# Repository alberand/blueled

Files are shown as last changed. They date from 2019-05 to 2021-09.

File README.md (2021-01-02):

## Blueled - Bluetooth LED strip controller

This repo has hardware and firmware for Bluetooth LED strip controller based on
atmega328p (the same as in Arduino Nano).

Features:

* Android Application (not started yet)
* Custom colors and gradients
* ~15 different pre-set animation
* Over-The-Air Updates
* Python interface (to control it from PC)
* Save latest state between power on/off
* Up to 100 LEDs on full brightness (WS2812B)

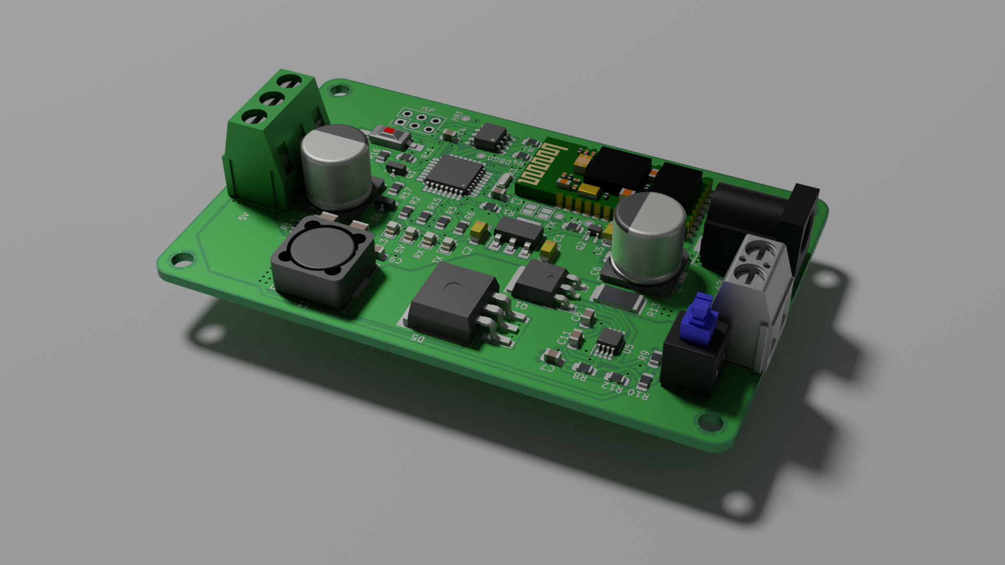
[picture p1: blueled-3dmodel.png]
PCB 3D Render


#### Notes (to refactor)

Be careful with connection between programmer Arduino and target Arduino. I had
a lot of corrupted bytes during uploading bootloader/application with ISCP.

Add bluetooth:

    $ sudo systemctl start bluetooth
    $ sudo bluetoothctl
    $ power on
    $ scan on
    $ # You will see MAC of your HC-05
    $ trust <MAC>
    $ pair <MAC>
    $ # It will ask for pin
    $ # That's all!

Load rfcomm kernel module:

    sudo modprobe rfcomm 

Create serial port:

    sudo rfcomm bind rfcomm0 <MAC>

How to sniff bluetooth:
https://github.com/snarlistic/jpnevulator

    jpnevulator --tty=/dev/blueled --read --ascii

In case of problems with PC's bluetooth module try:

1. power on/off module through the bluetoothctl session
2. sudo rfkill unblock all

https://gist.github.com/0/c73e2557d875446b9603

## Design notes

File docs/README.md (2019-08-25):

A lot of interesting articles at [1]

### Guides

Short instructions

#### How to get into AT mode

1. Upload serial-passthrough to your MCU
2. Connect to the bluetooth with Phone/another HC-05 to make sure that
   communication works
3. Put PIO11 high. Device will stop to reponse on serial link
4. Put RESET pin low
5. Put RESET pin high
6. Now you are in AT mode. Configure HC-05
7. Put PIO11 low
8. Reset chip again

### Notes

#### HC-Status PIO9

Seems to work but with delays.

### References

[1]: https://www.microchip.com/wwwproducts/en/ATSHA204A

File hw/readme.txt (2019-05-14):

Screw terminal:
https://www.gme.cz/svorkovnice-tl201v-03p-gs

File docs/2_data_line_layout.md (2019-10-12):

Author: Andrey Albershteyn
Date: 28.07.19
Status: Good Enough [Thrown away/Good Enough/Fully Solved]
Tags: hardware, layout

### Brief 

How to layout data line to the led strip? It is quite fast

### Timeline - Analysis & Solution

**[12.10.19]**

According to [this answer][1] the speed at which my device is operating is so
slow that it shouldn't be an issue for me. There are two main points to
consider:

* Signal integrity
* EMC

EMC can be caused by bad layout. 

* The shorter the line is the better. 
* Less vias better
* No sharp bends
[There][2] are a few good points on lay outing data lines

Signal integrity should be a problem in my case as it depends on slew/fall rate
which is quite slow in my case. 

There is no crosstalk in my case.

### References:

[1]: https://electronics.stackexchange.com/questions/9819/how-should-i-route-spi-lines
[2]: https://www.cypress.com/file/196526/download

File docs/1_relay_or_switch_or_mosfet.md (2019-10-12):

Author: Andrey Albershteyn
Date: 28.07.19
Status: Good Enough
Tags: feature, circuit-power-off

### Brief 

How to power off the whole device? With switch, relay or something else?

### Timeline - Analysis & Solution

**[28.07.19]**

I want to completely power off the circuit as I assume it more safe. No current
no problems. The following factors play role:

    * Humidity can create short circuit
    * High environment temperature + overheat on the output terminal
    * Low quality of Chinese components
    * Bug in the software (not fully disable led strip)
    * etc????

**[28.07.19]**

I find a few way how to power off the circuit:

    * Switch
    * Relay
    * MOSFET

**Switch** - very simple and cheap solution. However, the current in the circuit
is 5A. Therefore, I need some reliable high current switch. Unfortunately, all
of them are quite big for such a small device.

**Relay** - small, cheap, in combination with a small switch will give the same
functionality. The disadvantage is the *cwak* noise.

**MOSFET** - requires radiator which quite big.

**[29.07.19]**

According to this [1] using relay we get unwanted electromagnetic radiation
which is can be a problem for Bluetooth. I don't think it will broke it
completely but can decrease distance and quality of signal. The most of the
advantages of the relay doesn't suite for this application (such as AC
switching, isolation, robustness)

Mosfet is small and cheap and looks like it can be used as a switch. So, I don't
see why not use for this project.

I decided to you P-MOSFET. AOD4185L MOSFET P Trench 40V 40A 3V @ 250uA 15 mΩ @
20A,10V TO-252-2(DPAK) RoHS

Proof that it is used as reverse polarity [2]

### References

[1]: https://electronics.stackexchange.com/questions/10092/relay-vs-transistor
[2]: https://electronics.stackexchange.com/questions/61692/reverse-polarity-protection

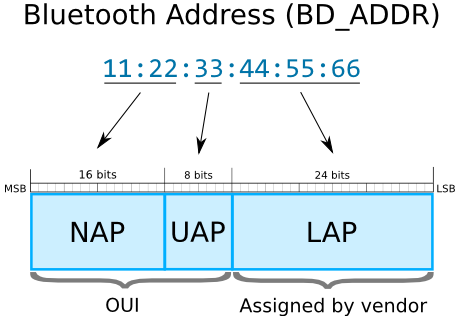
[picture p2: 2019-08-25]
docs/bluetooth-address-structure-nap-uap-lap.png

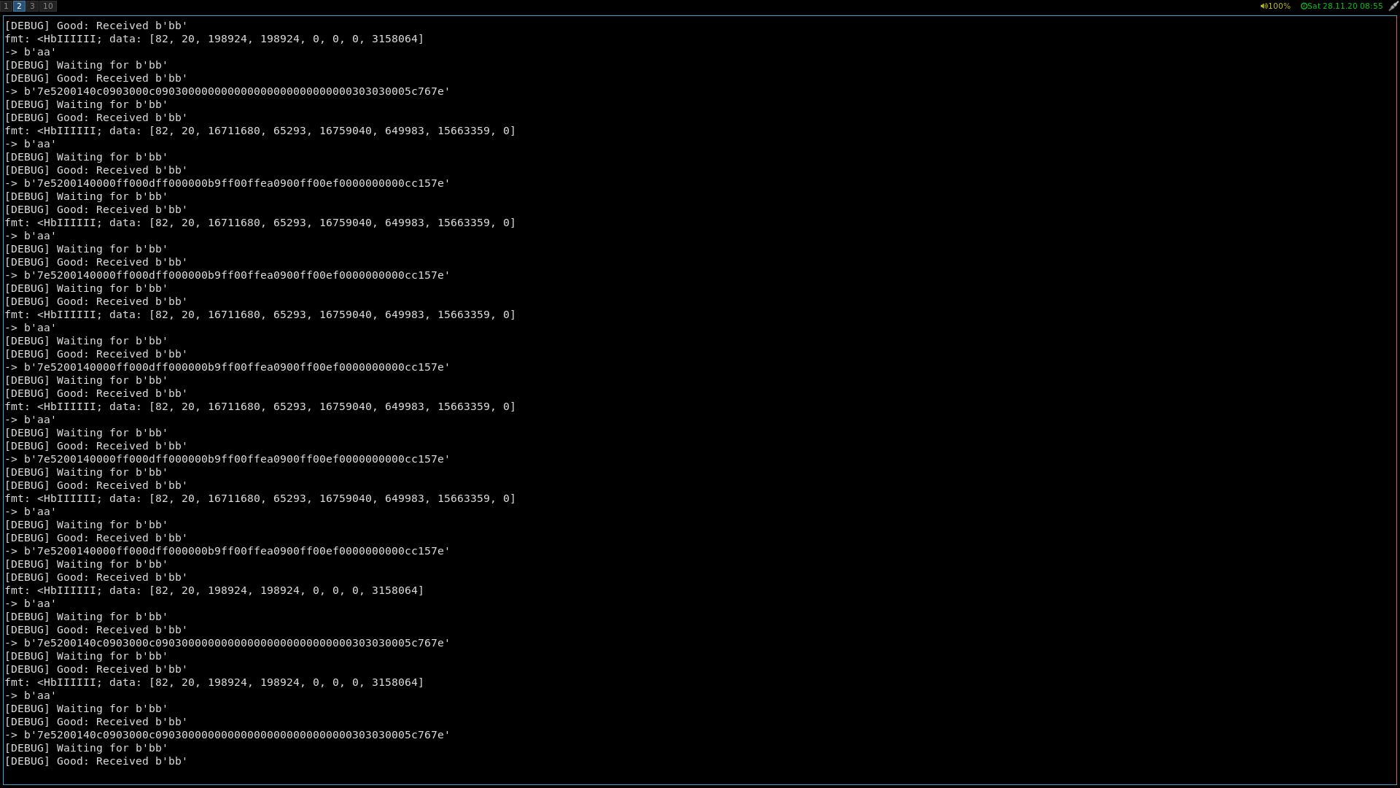
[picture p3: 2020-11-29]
scripts/monitor-1.png

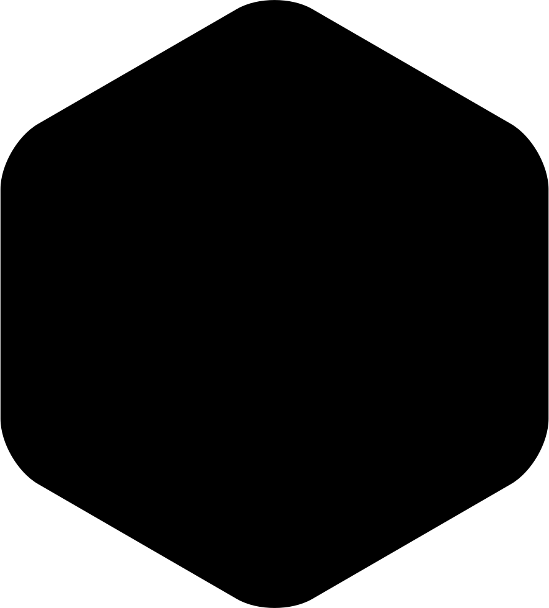
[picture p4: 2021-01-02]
hw/hexagon.png

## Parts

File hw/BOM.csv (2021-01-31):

Reference | Value | Footprint | Datasheet | Distributor | Manuf. Part | Field4 | Field6 | Field7 | Field8
J2 | LED Strip | TerminalBlock:TerminalBlock_bornier-3_P5.08mm | https://datasheet.lcsc.com/szlcsc/2004291906_Ningbo-Xinlaiya-Elec-XY2500R-D-5-08-3P_C505825.pdf | lcsc.com | XY2500R-D-5.08-3P
J1 | DC 5.5 - 42V | Connector_BarrelJack:BarrelJack_Horizontal | https://datasheet.lcsc.com/szlcsc/1912111437_XKB-Enterprise-DC-005-5A-2-0_C381116.pdf | lcsc.com | DC-005-5A-2.0
J3 | ICSP | Connector_PinHeader_2.54mm:PinHeader_2x03_P2.54mm_Vertical | ~
D3 | TX | LED_SMD:LED_0805_2012Metric_Pad1.15x1.40mm_HandSolder | https://datasheet.lcsc.com/szlcsc/1811141223_TOGIALED-TJ-S1608SW6TGLC2G-A5_C192316.pdf | lcsc.com | TJ-S1608SW6TGLC2R-A5
R6 | 150 | Resistor_SMD:R_0805_2012Metric_Pad1.15x1.40mm_HandSolder | https://datasheet.lcsc.com/szlcsc/YAGEO-RC0805FR-07150RL_C114523.pdf | lcsc.com | RC0805FR-07150RL
D2 | RX | LED_SMD:LED_0805_2012Metric_Pad1.15x1.40mm_HandSolder | https://datasheet.lcsc.com/szlcsc/1811141223_TOGIALED-TJ-S1608SW6TGLC2G-A5_C192316.pdf | lcsc.com | TJ-S1608SW6TGLC2R-A5
R3 | 150 | Resistor_SMD:R_0805_2012Metric_Pad1.15x1.40mm_HandSolder | https://datasheet.lcsc.com/szlcsc/YAGEO-RC0805FR-07150RL_C114523.pdf | lcsc.com | RC0805FR-07150RL
U2 | HC-05 | MOUDLE-BLUETOOTH-HC-05_34P-27X13MM_:BT34P-SMD-1.5-26.9X13.0X2.2MM | https://components101.com/sites/default/files/component_datasheet/HC-05%20Datasheet.pdf | aliexpress.com |  | Unavailable | SOIC-14 | HuiCheng | None
DBG1 | DBG-HC-PWR | TestPoint:TestPoint_Pad_D1.0mm | ~
JP1 | Jumper_NC_Small | Jumper:SolderJumper-2_P1.3mm_Bridged_Pad1.0x1.5mm | ~
JP2 | Jumper_NC_Small | Jumper:SolderJumper-2_P1.3mm_Bridged_Pad1.0x1.5mm | ~
J4 | DC 5.5 - 42V | TerminalBlock:TerminalBlock_bornier-2_P5.08mm | https://datasheet.lcsc.com/szlcsc/1912251632_Ningbo-Kangnex-Elec-WJ15EDGRC-3-81-2P_C8387.pdf | lcsc.com | WJ15EDGRC-3.81-2P
C5 | 22uF | Capacitor_Tantalum_SMD:CP_EIA-3216-18_Kemet-A_Pad1.58x1.35mm_HandSolder | https://datasheet.lcsc.com/szlcsc/1809131544_Vishay-Intertech-593D226X9004A2TE3_C215881.pdf | lcsc.com | 593D226X9004A2TE3
R5 | 1k | Resistor_SMD:R_0805_2012Metric_Pad1.15x1.40mm_HandSolder | https://datasheet.lcsc.com/szlcsc/1810010118_YAGEO-RC0805FR-071KL_C95781.pdf | lcsc.com | RC0805FR-071KL
DBG2 | DBG-HC-RST | TestPoint:TestPoint_Pad_D1.0mm | ~
D6 | BAS40-04 | Package_TO_SOT_SMD:SOT-23 | http://www.vishay.com/docs/85701/bas40v.pdf | lcsc.com | BAS40-04
H1 | MountingHole_Pad | MountingHole:MountingHole_3.2mm_M3 | ~
H2 | MountingHole_Pad | MountingHole:MountingHole_3.2mm_M3 | ~
H3 | MountingHole_Pad | MountingHole:MountingHole_3.2mm_M3 | ~
H4 | MountingHole_Pad | MountingHole:MountingHole_3.2mm_M3 | ~
C12 | 1000uF | Capacitor_SMD:CP_Elec_10x10 | https://datasheet.lcsc.com/szlcsc/1912111437_Lelon-VEU102M0JTR-1010_C249735.pdf | lcsc.com | VEU102M0JTR-1010
C6 | 33uF | Capacitor_SMD:CP_Elec_10x10 | https://datasheet.lcsc.com/szlcsc/1809291341_Lelon-VZH330M2ATR-1010_C249899.pdf | lcsc.com | VZH330M2ATR-1010
Q1 | Q_PMOS_SDG | Package_TO_SOT_SMD:TO-252-3_TabPin4 | https://datasheet.lcsc.com/szlcsc/Alpha-Omega-Semicon-AOS-AOD4185_C77993.pdf | lcsc.com | AOD4185L
C13 | 47uF | Capacitor_SMD:C_1210_3225Metric_Pad1.42x2.65mm_HandSolder | https://datasheet.lcsc.com/szlcsc/1912111437_TDK-C3225X5R0J476MT000N_C338024.pdf | lcsc.com | C3225X5R0J476MT000N
C1 | 10uF | Capacitor_Tantalum_SMD:CP_EIA-3216-18_Kemet-A_Pad1.58x1.35mm_HandSolder | https://datasheet.lcsc.com/szlcsc/AVX-TAJA106K016RNJ_C7171.pdf | lcsc.com | TAJA106K016RNJ
D4 | +5V | LED_SMD:LED_0805_2012Metric_Pad1.15x1.40mm_HandSolder | https://datasheet.lcsc.com/szlcsc/1811141223_TOGIALED-TJ-S1608SW6TGLC2G-A5_C192316.pdf | lcsc.com | TJ-S1608SW6TGLC2G-A5
R15 | 470 | Resistor_SMD:R_0805_2012Metric_Pad1.15x1.40mm_HandSolder | https://datasheet.lcsc.com/szlcsc/1810311431_YAGEO-RC0805FR-07470RL_C114564.pdf | lcsc.com | RC0805FR-07470RL
R14 | 0.27 | Resistor_SMD:R_0805_2012Metric_Pad1.15x1.40mm_HandSolder | https://datasheet.lcsc.com/szlcsc/2009282237_YAGEO-RL0805JR-070R27L_C705550.pdf | lcsc.com | RL0805JR-070R27L
R13 | 0.01 | Resistor_SMD:R_2512_6332Metric_Pad1.52x3.35mm_HandSolder | https://datasheet.lcsc.com/szlcsc/2008171235_YAGEO-RL2512JK-070R01L_C705618.pdf | lcsc.com | RL2512JK-070R01L
C7 | 680nF | Capacitor_SMD:C_0805_2012Metric_Pad1.15x1.40mm_HandSolder | https://datasheet.lcsc.com/szlcsc/2004221632_TDK-C2012X7S2A684KT000N_C516764.pdf | lcsc.com | C2012X7S2A684KT000N
U5 | LM25085MM | Package_SO:VSSOP-8_3.0x3.0mm_P0.65mm | http://www.ti.com/lit/ds/symlink/lm25085.pdf | lcsc.com | LM25085MM/NOPB
R10 | 10k | Resistor_SMD:R_0805_2012Metric_Pad1.15x1.40mm_HandSolder | https://datasheet.lcsc.com/szlcsc/1810201611_YAGEO-RC0805FR-0710KL_C84376.pdf | lcsc.com | RC0805FR-0710KL
C8 | 0.47uF | Capacitor_SMD:C_0805_2012Metric_Pad1.15x1.40mm_HandSolder | https://datasheet.lcsc.com/szlcsc/2009111606_TDK-C2012X7R1C474KT000N_C694187.pdf | lcsc.com | C2012X7R1C474KT000N
R8 | 90.9 | Resistor_SMD:R_0805_2012Metric_Pad1.15x1.40mm_HandSolder | https://datasheet.lcsc.com/szlcsc/1810301711_KOA-Speer-Elec-RK73B2ATTD102J_C159911.pdf | lcsc.com | RK73B2ATTD102J
C11 | 1nF | Capacitor_SMD:C_0805_2012Metric_Pad1.15x1.40mm_HandSolder | https://datasheet.lcsc.com/szlcsc/1912111437_TDK-C2012X7R2A102KT020S_C415298.pdf | lcsc.com | C2012X7R2A102KT020S
R12 | 2.1k | Resistor_SMD:R_0805_2012Metric_Pad1.15x1.40mm_HandSolder | https://datasheet.lcsc.com/szlcsc/2001062136_YAGEO-RC0805FR-072K1L_C273922.pdf | lcsc.com | RC0805FR-072K1L
R9 | 3.4k | Resistor_SMD:R_0805_2012Metric_Pad1.15x1.40mm_HandSolder | https://datasheet.lcsc.com/szlcsc/YAGEO-AC0805FR-073K4L_C228795.pdf | lcsc.com | RC0805FR-073K4L
C10 | 47uF | Capacitor_SMD:C_1210_3225Metric_Pad1.42x2.65mm_HandSolder | https://datasheet.lcsc.com/szlcsc/1912111437_TDK-C3225X5R0J476MT000N_C338024.pdf | lcsc.com | C3225X5R0J476MT000N
L1 | 15uH | blueled:SMMS1350-150M | https://datasheet.lcsc.com/szlcsc/1912111437_Sunlord-MWSA1004S-150MT_C408488.pdf | lcsc.com | MWSA1004S-150MT
D5 | MBRB2060 | Package_TO_SOT_SMD:TO-263-3_TabPin2 | https://datasheet.lcsc.com/szlcsc/Sangdest-Microelectronicstronic-Nanjing-MBRB2060CT_C260296.pdf | lcsc.com | MBRB2060CT
C9 | 4700pF | Capacitor_SMD:C_0805_2012Metric_Pad1.15x1.40mm_HandSolder | https://datasheet.lcsc.com/szlcsc/1912111437_TDK-C2012C0G1H472JT0H0N_C342964.pdf | lcsc.com | C2012C0G1H472JT0H0N
S1 | SWITCH-DPDT-PTH-GPI-152-3013 | blueled:XKB7070-Z | https://datasheet.lcsc.com/szlcsc/2002271810_XKB-Enterprise-XKB7070-Z_C318863.pdf | lcsc.com | XKB7070-Z | SWCH-10554
C2 | 22uF | Capacitor_Tantalum_SMD:CP_EIA-3216-18_Kemet-A_Pad1.58x1.35mm_HandSolder | https://datasheet.lcsc.com/szlcsc/1809131544_Vishay-Intertech-593D226X9004A2TE3_C215881.pdf | lcsc.com | 593D226X9004A2TE3
D1 | +3.3V | LED_SMD:LED_0805_2012Metric_Pad1.15x1.40mm_HandSolder | https://datasheet.lcsc.com/szlcsc/1811141223_TOGIALED-TJ-S1608SW6TGLC2G-A5_C192316.pdf | lcsc.com | TJ-S1608SW6TGLC2G-A5
R2 | 150 | Resistor_SMD:R_0805_2012Metric_Pad1.15x1.40mm_HandSolder | https://datasheet.lcsc.com/szlcsc/YAGEO-RC0805FR-07150RL_C114523.pdf | lcsc.com | RC0805FR-07150RL
U3 | AMS1117-3.3 | Package_TO_SOT_SMD:SOT-223 | http://www.ti.com/lit/ds/symlink/lm1117.pdf | lcsc.com | AMS1117-3.3
R7 | 1k | Resistor_SMD:R_0805_2012Metric_Pad1.15x1.40mm_HandSolder | https://datasheet.lcsc.com/szlcsc/1810010118_YAGEO-RC0805FR-071KL_C95781.pdf | lcsc.com | RC0805FR-071KL
C4 | 100n | Capacitor_SMD:C_0805_2012Metric_Pad1.15x1.40mm_HandSolder | https://datasheet.lcsc.com/szlcsc/1810191215_Samsung-Electro-Mechanics-CL21B104KBCNNNC_C1711.pdf | lcsc.com | CL21B104KBCNNNC
R4 | 1k | Resistor_SMD:R_0805_2012Metric_Pad1.15x1.40mm_HandSolder | https://datasheet.lcsc.com/szlcsc/1810010118_YAGEO-RC0805FR-071KL_C95781.pdf | lcsc.com | RC0805FR-071KL
U4 | AT25SF081 | Package_SO:SOIC-8_3.9x4.9mm_P1.27mm | https://www.adestotech.com/wp-content/uploads/DS-AT25SF081_045.pdf | lcsc.com | AT25SF081-SHD-T
R17 | 1k | Resistor_SMD:R_0805_2012Metric_Pad1.15x1.40mm_HandSolder | https://datasheet.lcsc.com/szlcsc/1810010118_YAGEO-RC0805FR-071KL_C95781.pdf | lcsc.com | RC0805FR-071KL
R16 | 1k | Resistor_SMD:R_0805_2012Metric_Pad1.15x1.40mm_HandSolder | https://datasheet.lcsc.com/szlcsc/1810010118_YAGEO-RC0805FR-071KL_C95781.pdf | lcsc.com | RC0805FR-071KL
Q3 | BSS138 | Package_TO_SOT_SMD:SOT-23 | https://datasheet.lcsc.com/szlcsc/AnBon-BSS138_C193019.pdf | lcsc.com | BSS138
R11 | 470 | Resistor_SMD:R_0805_2012Metric_Pad1.15x1.40mm_HandSolder | https://datasheet.lcsc.com/szlcsc/1810311431_YAGEO-RC0805FR-07470RL_C114564.pdf | lcsc.com | RC0805FR-07470RL
HRT1 | Heartbeat | TestPoint:TestPoint_Pad_D1.0mm | ~
X1 | CSTCE | blueled:Resonator_SMD_muRata_CSTNE_3Pin_3.2x1.3mm | https://datasheet.lcsc.com/szlcsc/1912111437_Murata-Electronics-CSTNE8M00G55Z000R0_C341524.pdf | lcsc.com | CSTNE8M00G55Z000R0
R1 | 1k | Resistor_SMD:R_0805_2012Metric_Pad1.15x1.40mm_HandSolder | https://datasheet.lcsc.com/szlcsc/1810010118_YAGEO-RC0805FR-071KL_C95781.pdf | lcsc.com | RC0805FR-071KL
SW2 | PUSH | Button_Switch_SMD:SW_SPST_FSMSM | https://datasheet.lcsc.com/szlcsc/1811082126_Korean-Hroparts-Elec-K2-1107ST-A4SW-06_C118141.pdf | lcsc.com | K2-1107ST-A4SW-06
DBG0 | Debug | TestPoint:TestPoint_Pad_D1.0mm | ~
C3 | 100n | Capacitor_SMD:C_0805_2012Metric_Pad1.15x1.40mm_HandSolder | https://datasheet.lcsc.com/szlcsc/1810191215_Samsung-Electro-Mechanics-CL21B104KBCNNNC_C1711.pdf | lcsc.com | CL21B104KBCNNNC
U1 | ATmega328P-AU | Package_QFP:TQFP-32_7x7mm_P0.8mm | http://ww1.microchip.com/downloads/en/DeviceDoc/ATmega328_P%20AVR%20MCU%20with%20picoPower%20Technology%20Data%20Sheet%2040001984A.pdf | lcsc.com | ATmega328P-AU
Q4 | Q_PMOS_GSD | Package_TO_SOT_SMD:SOT-23 | https://datasheet.lcsc.com/szlcsc/1912111437_UMW-Youtai-Semiconductor-Co-Ltd-IRLML6402_C347504.pdf | lcsc.com | IRLML6402

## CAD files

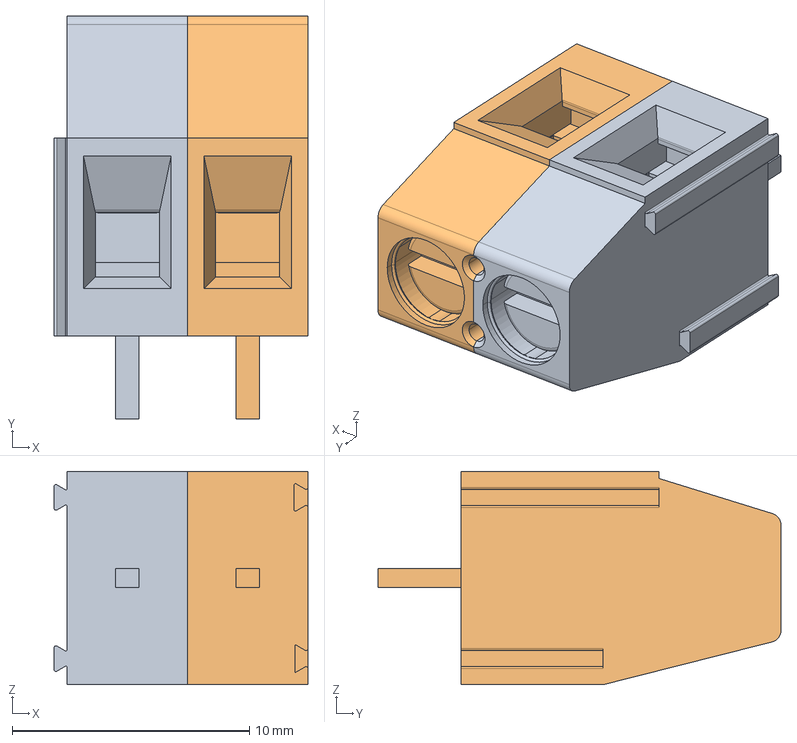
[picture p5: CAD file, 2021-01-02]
hw/3dmodels/terminal-block-2.stp
10.7 x 17.0 x 9.00 mm

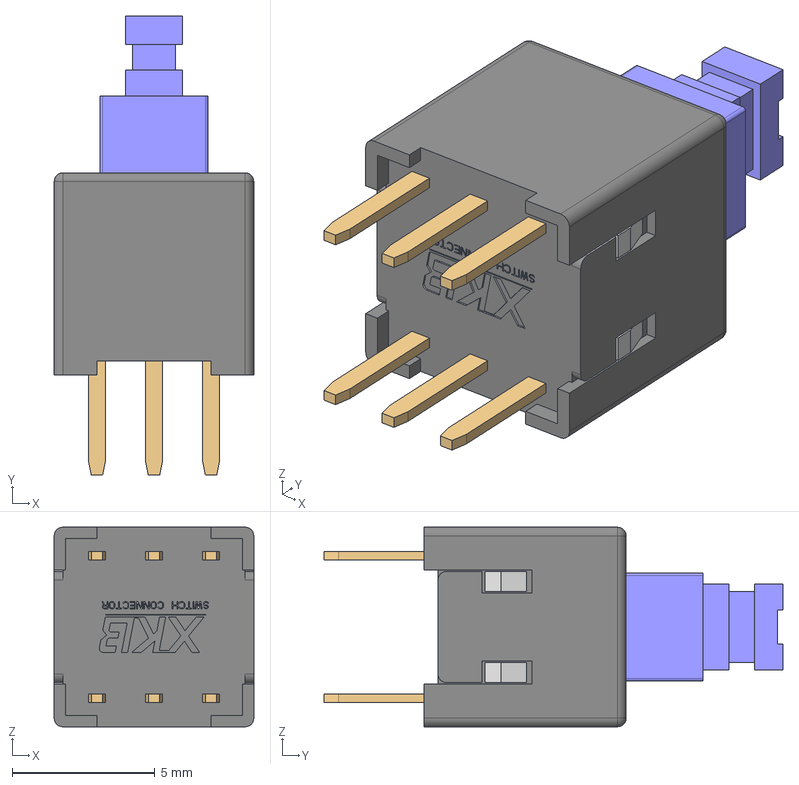
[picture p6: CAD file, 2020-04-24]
hw/3dmodels/xkb7070-z.step
7.00 x 16.1 x 7.00 mm

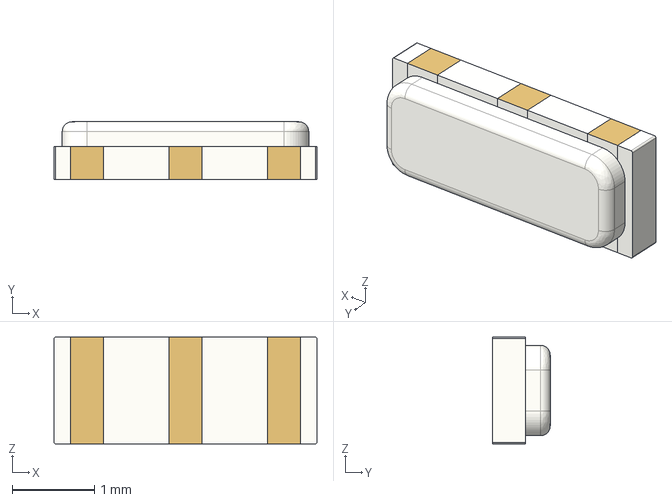
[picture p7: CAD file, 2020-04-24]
hw/3dmodels/CSTNE.step
3.20 x 0.7 x 1.30 mm

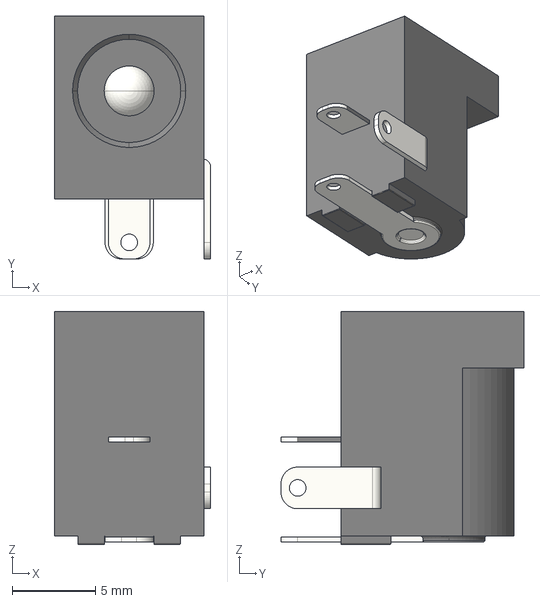
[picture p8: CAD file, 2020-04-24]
hw/3dmodels/dc-005-5a-2_0.step
9.40 x 14.6 x 14.0 mm

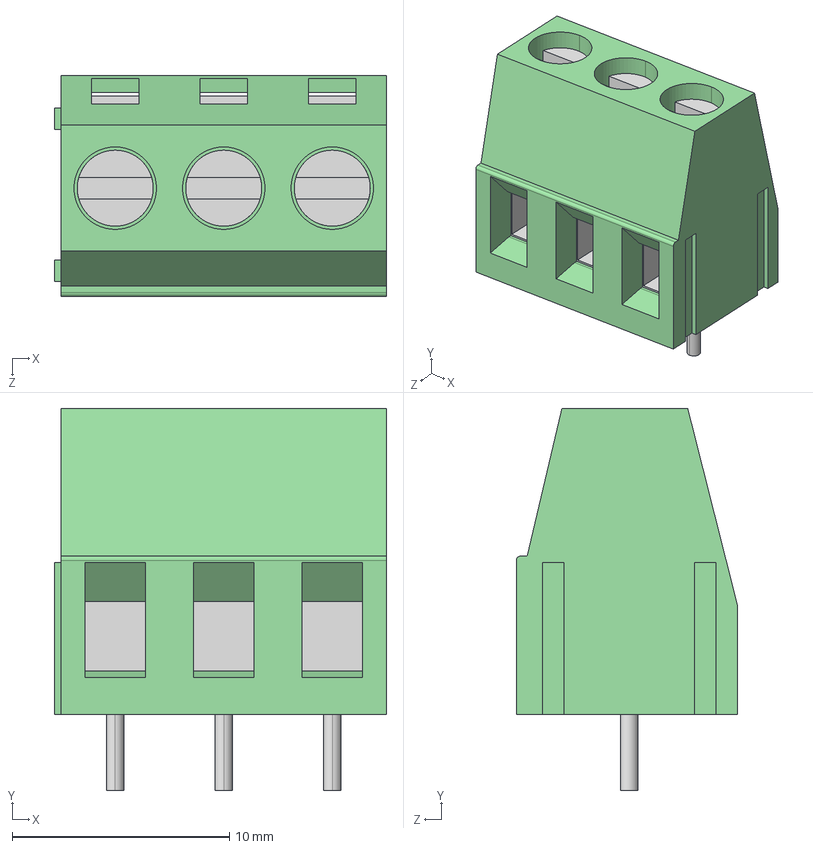
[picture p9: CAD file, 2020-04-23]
hw/3dmodels/kf120-5.0-3p.step
15.3 x 17.6 x 10.2 mm

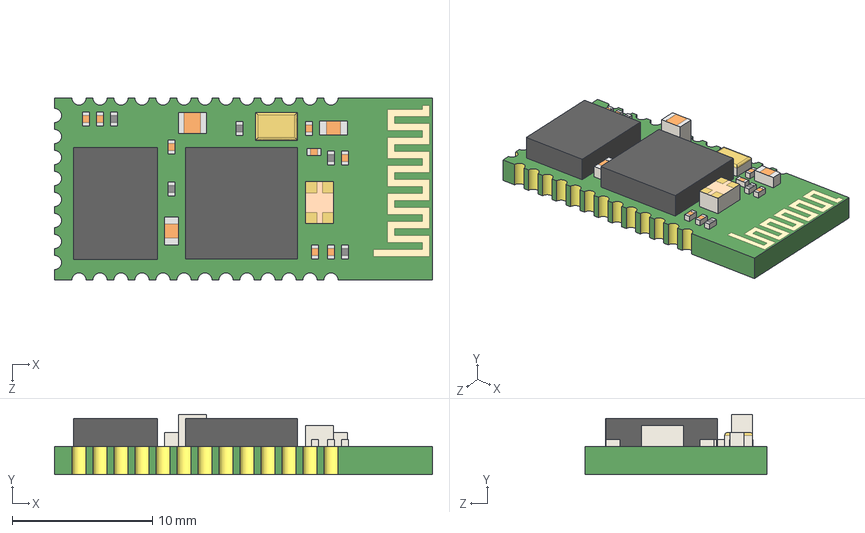
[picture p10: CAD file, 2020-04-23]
hw/3dmodels/HC-05.step
27.0 x 4.31 x 13.0 mm

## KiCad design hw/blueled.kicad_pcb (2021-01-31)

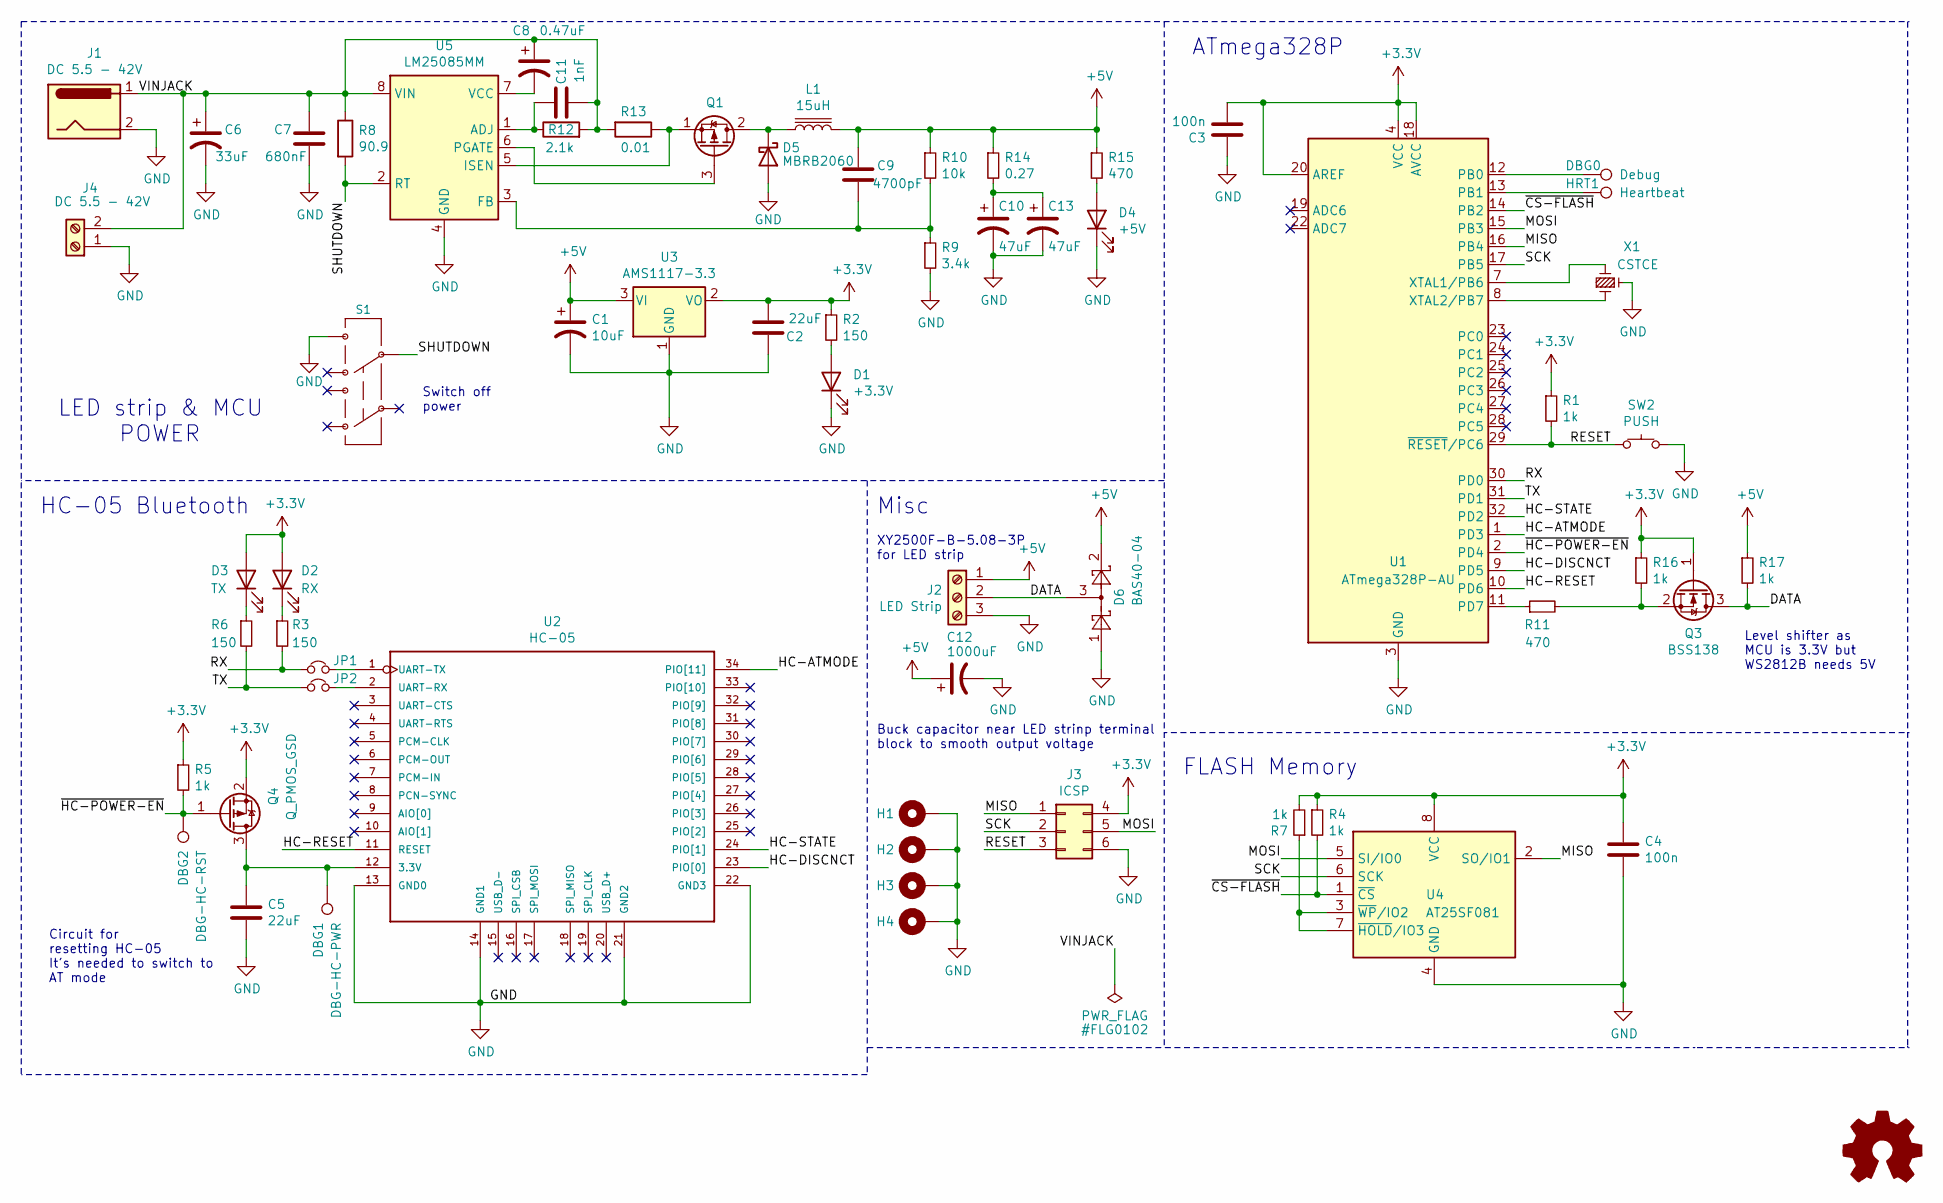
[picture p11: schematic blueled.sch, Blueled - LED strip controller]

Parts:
C1: 10uF; CP_EIA-3216-18_Kemet-A_Pad1.58x1.35mm_HandSolder; Manuf. Part TAJA106K016RNJ
C2, C5: 22uF; CP_EIA-3216-18_Kemet-A_Pad1.58x1.35mm_HandSolder; Manuf. Part 593D226X9004A2TE3
C3, C4: 100n; C_0805_2012Metric_Pad1.15x1.40mm_HandSolder; Manuf. Part CL21B104KBCNNNC
C6: 33uF; CP_Elec_10x10; Manuf. Part VZH330M2ATR-1010
C7: 680nF; C_0805_2012Metric_Pad1.15x1.40mm_HandSolder; Manuf. Part C2012X7S2A684KT000N
C8: 0.47uF; C_0805_2012Metric_Pad1.15x1.40mm_HandSolder; Manuf. Part C2012X7R1C474KT000N
C9: 4700pF; C_0805_2012Metric_Pad1.15x1.40mm_HandSolder; Manuf. Part C2012C0G1H472JT0H0N
C10, C13: 47uF; C_1210_3225Metric_Pad1.42x2.65mm_HandSolder; Manuf. Part C3225X5R0J476MT000N
C11: 1nF; C_0805_2012Metric_Pad1.15x1.40mm_HandSolder; Manuf. Part C2012X7R2A102KT020S
C12: 1000uF; CP_Elec_10x10; Manuf. Part VEU102M0JTR-1010
D1: +3.3V; LED_0805_2012Metric_Pad1.15x1.40mm_HandSolder; Manuf. Part TJ-S1608SW6TGLC2G-A5
D2: RX; LED_0805_2012Metric_Pad1.15x1.40mm_HandSolder; Manuf. Part TJ-S1608SW6TGLC2R-A5
D3: TX; LED_0805_2012Metric_Pad1.15x1.40mm_HandSolder; Manuf. Part TJ-S1608SW6TGLC2R-A5
D4: +5V; LED_0805_2012Metric_Pad1.15x1.40mm_HandSolder; Manuf. Part TJ-S1608SW6TGLC2G-A5
D5: MBRB2060; TO-263-3_TabPin2; Manuf. Part MBRB2060CT
D6: BAS40-04; SOT-23; Manuf. Part BAS40-04
DBG0: Debug; TestPoint_Pad_D1.0mm
DBG1: DBG-HC-PWR; TestPoint_Pad_D1.0mm
DBG2: DBG-HC-RST; TestPoint_Pad_D1.0mm
H1, H2, H3, H4: MountingHole_Pad; MountingHole_3.2mm_M3
HRT1: Heartbeat; TestPoint_Pad_D1.0mm
J1: DC 5.5 - 42V; BarrelJack_Horizontal; Manuf. Part DC-005-5A-2.0
J2: LED Strip; TerminalBlock_bornier-3_P5.08mm; Manuf. Part XY2500R-D-5.08-3P
J3: ICSP; PinHeader_2x03_P2.54mm_Vertical
J4: DC 5.5 - 42V; TerminalBlock_bornier-2_P5.08mm; Manuf. Part WJ15EDGRC-3.81-2P
JP1, JP2: Jumper_NC_Small; SolderJumper-2_P1.3mm_Bridged_Pad1.0x1.5mm
L1: 15uH; SMMS1350-150M; Manuf. Part MWSA1004S-150MT
Q1: Q_PMOS_SDG; TO-252-3_TabPin4; Manuf. Part AOD4185L
Q3: BSS138; SOT-23; Manuf. Part BSS138
Q4: Q_PMOS_GSD; SOT-23; Manuf. Part IRLML6402
R1, R4, R5, R7, R16, R17: 1k; R_0805_2012Metric_Pad1.15x1.40mm_HandSolder; Manuf. Part RC0805FR-071KL
R2, R3, R6: 150; R_0805_2012Metric_Pad1.15x1.40mm_HandSolder; Manuf. Part RC0805FR-07150RL
R8: 90.9; R_0805_2012Metric_Pad1.15x1.40mm_HandSolder; Manuf. Part RK73B2ATTD102J
R9: 3.4k; R_0805_2012Metric_Pad1.15x1.40mm_HandSolder; Manuf. Part RC0805FR-073K4L
R10: 10k; R_0805_2012Metric_Pad1.15x1.40mm_HandSolder; Manuf. Part RC0805FR-0710KL
R11, R15: 470; R_0805_2012Metric_Pad1.15x1.40mm_HandSolder; Manuf. Part RC0805FR-07470RL
R12: 2.1k; R_0805_2012Metric_Pad1.15x1.40mm_HandSolder; Manuf. Part RC0805FR-072K1L
R13: 0.01; R_2512_6332Metric_Pad1.52x3.35mm_HandSolder; Manuf. Part RL2512JK-070R01L
R14: 0.27; R_0805_2012Metric_Pad1.15x1.40mm_HandSolder; Manuf. Part RL0805JR-070R27L
S1: SWITCH-DPDT-PTH-GPI-152-3013; XKB7070-Z; Manuf. Part XKB7070-Z
SW2: PUSH; SW_SPST_FSMSM; Manuf. Part K2-1107ST-A4SW-06
U1: ATmega328P-AU; TQFP-32_7x7mm_P0.8mm; Manuf. Part ATmega328P-AU
U2: HC-05; BT34P-SMD-1.5-26.9X13.0X2.2MM
U3: AMS1117-3.3; SOT-223; Manuf. Part AMS1117-3.3
U4: AT25SF081; SOIC-8_3.9x4.9mm_P1.27mm; Manuf. Part AT25SF081-SHD-T
U5: LM25085MM; VSSOP-8_3.0x3.0mm_P0.65mm; Manuf. Part LM25085MM/NOPB
X1: CSTCE; Resonator_SMD_muRata_CSTNE_3Pin_3.2x1.3mm; Manuf. Part CSTNE8M00G55Z000R0

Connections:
+3V3: C2.2, C3.2, C4.1, D2.2 (A), D3.2 (A), J3.4, Q3.1 (G), Q4.2 (S), R1.1, R2.1, R4.1, R5.1, R7.2, R16.1, U1.4 (VCC), U1.6 (VCC), U1.18 (AVCC), U1.20 (AREF), U3.2 (VO), U4.8 (VCC); also elsewhere on the board
+5V: C1.1, C9.1, C12.1, D6.2, J2.1, L1.2, R10.1, R14.1, R15.1, R17.1, U3.3 (VI)
/DATA: D6.3, J2.2, Q3.3 (D), R17.2
/HC-ATMODE: U1.1 (PD3), U2.34 (PIO[11])
/HC-DISCNCT: U1.9 (PD5), U2.23 (PIO[0])
/HC-RESET: U1.10 (PD6), U2.11 (RESET)
/HC-STATE: U1.32 (PD2), U2.24 (PIO[1])
/MISO: J3.1, U1.16 (PB4), U4.2 (SO/IO1)
/MOSI: J3.5, U1.15 (PB3), U4.5 (SI/IO0)
/RESET: J3.3, R1.2, SW2.1, U1.29 (~RESET~/PC6)
/RX: JP1.1, R3.2, U1.30 (PD0)
/SCK: J3.2, U1.17 (PB5), U4.6 (SCK)
/SHUTDOWN: R8.2, S1.5, U5.2 (RT)
/TX: JP2.1, R6.2, U1.31 (PD1)
/VINJACK: C6.1, C7.1, C8.1, C11.1, J1.1, J4.2, R8.1, R12.2, R13.2, U5.8 (VIN); also elsewhere on the board
/~CS-FLASH: R4.2, U1.14 (PB2), U4.1 (~CS)
/~HC-POWER-EN: DBG2.1, Q4.1 (G), R5.2, U1.2 (PD4)
GND: C1.2, C2.1, C3.1, C4.2, C5.2, C6.2, C7.2, C10.2, C12.2, C13.2, D1.1 (K), D4.1 (K), D5.2 (A), D6.1, H1.1, H2.1, H3.1, H4.1, J1.2, J2.3, J3.6, J4.1, R9.2, S1.6, SW2.2, U1.3 (GND), U1.5 (GND), U1.21 (GND), U2.13 (GND0), U2.14 (GND1), U2.21 (GND2), U2.22 (GND3), U3.1 (GND), U4.4 (GND), U5.4 (GND), X1.2; also elsewhere on the board
unnamed: C5.1, DBG1.1, Q4.3 (D), U2.12 (3.3V)
unnamed: C8.2, U5.7 (VCC)
unnamed: C9.2, R9.1, R10.2, U5.3 (FB)
unnamed: C10.1, C13.1, R14.2
unnamed: C11.2, R12.1, U5.1 (ADJ)
unnamed 23: D1.2 (A), R2.2; also elsewhere on the board
unnamed 24: D2.1 (K), R3.1; also elsewhere on the board
unnamed 25: D3.1 (K), R6.1; also elsewhere on the board
unnamed 26: D4.2 (A), R15.2; also elsewhere on the board
unnamed: D5.1 (K), L1.1, Q1.2 (D)
unnamed: DBG0.1, U1.12 (PB0)
unnamed: HRT1.1, U1.13 (PB1)
unnamed: JP1.2, U2.1 (UART-TX)
unnamed: JP2.2, U2.2 (UART-RX)
unnamed: Q1.1 (S), R13.1, U5.5 (ISEN)
unnamed: Q1.3 (G), U5.6 (PGATE)
unnamed: Q3.2 (S), R11.2, R16.2
unnamed: R7.1, U4.3 (~WP~/IO2), U4.7 (~HOLD~/IO3)
unnamed: R11.1, U1.11 (PD7)
unnamed: U1.7 (XTAL1/PB6), X1.3
unnamed: U1.8 (XTAL2/PB7), X1.1

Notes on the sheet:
Misc
HC-05 Bluetooth
LED strip & MCU POWER
Buck capacitor near LED strinp terminal block to smooth output voltage
Circuit for resetting HC-05 It's needed to switch to AT mode
XY2500F-B-5.08-3P for LED strip
Switch off power
FLASH Memory
ATmega328P
Level shifter as MCU is 3.3V but WS2812B needs 5V

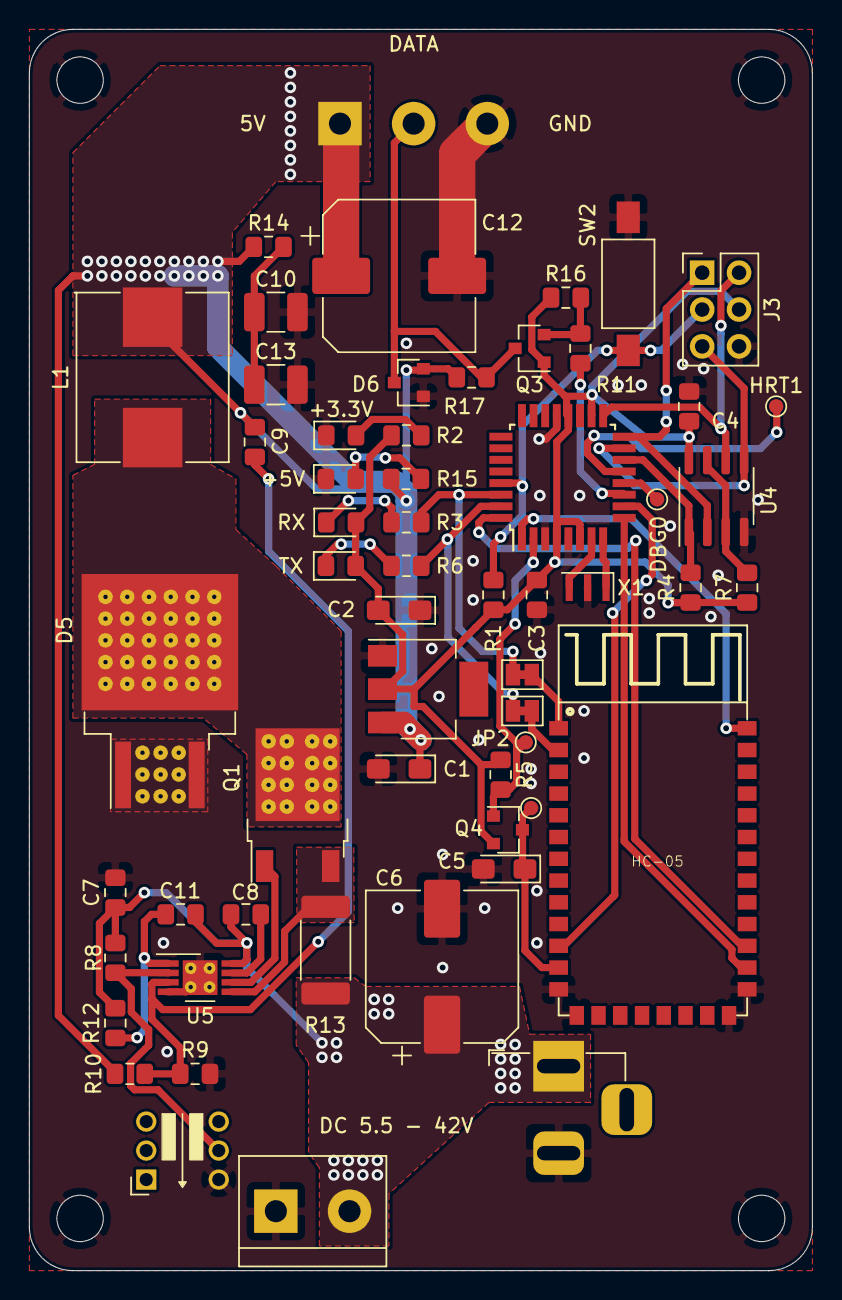
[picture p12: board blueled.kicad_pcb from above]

Board: 2 copper layers, 54.0 x 85.6 mm, 62 parts (0 on the bottom side), 39 nets.

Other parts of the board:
+3.3V: +3.3V; LED_0805_2012Metric_Pad1.15x1.40mm_HandSolder
+5V: +5V; LED_0805_2012Metric_Pad1.15x1.40mm_HandSolder
DC 5.5 - 42V: DC 5.5 - 42V; BarrelJack_Horizontal
RX: RX; LED_0805_2012Metric_Pad1.15x1.40mm_HandSolder
TX: TX; LED_0805_2012Metric_Pad1.15x1.40mm_HandSolder

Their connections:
+3V3: RX.2, TX.2; also elsewhere on the board
/VINJACK: DC 5.5 - 42V.1; also elsewhere on the board
GND: +3.3V.1, +5V.1, DC 5.5 - 42V.2; also elsewhere on the board
unnamed 23: +3.3V.2; also elsewhere on the board
unnamed 24: RX.1; also elsewhere on the board
unnamed 25: TX.1; also elsewhere on the board
unnamed 26: +5V.2; also elsewhere on the board

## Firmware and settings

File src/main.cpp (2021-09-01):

#define F_CPU 8000000L
#include <stdio.h>
#include <stdarg.h>

#include <avr/wdt.h>
#include <avr/interrupt.h>
#include <Arduino.h>
#include <EEPROM.h>
#include <FastLED.h>
#include <ledfx.h>

#include "simpap.hpp"
#include "common.hpp"

#define DEBUG

// Software-Hardware configuration
// Always 5V
#define MAX_VOLTS 5
#define MAX_AMPS 5
// Therefore, 25 W in total

// Application related
#define DATA_PIN PD7
#define PIN_RESET PD3
#define PIN_DEBUG PD0
#define PIN_HEARTBEAT 9
#define CYCLE_MAX_DURATION 100

// Communication
#define COMMAND_OFFSET 0
#define PARAMS_NUM_OFFSET 2
#define PAYLOAD_OFFSET 3
#define MAX_PARAMS 20

// In updates per second (Hz)
#define BASE_FREQ 100
#define BASE_PERIOD (1000/BASE_FREQ)

// Constants for saving application state to memory
#define MEM_BASE_ADDRESS 0x0
#define MEM_NEW_STATE_ADDRESS (MEM_BASE_ADDRESS + 0x0)
#define MEM_STATE_ADDRESS (MEM_NEW_STATE_ADDRESS + sizeof(bool))
#define MEM_ANIMATION_STATE_ADDRESS (MEM_STATE_ADDRESS + sizeof(state))
#define MEM_ANIMATION_PARAMS_ADDRESS (MEM_ANIMATION_STATE_ADDRESS + sizeof(ledfx_state))

#define MAX_LEDS 50

#define START_COMM 0xAA
#define ACK 0xBB
#define COMM_INIT_MSG 0x20
#define COMM_SET_BRIGHT_MSG 0x21

/*! Communication state */
static bool in_comm = false;

/*! Heart beat state */
static int heart_state = HIGH;

/*! Trigger for updating the LEDs */
static volatile bool update = false;

// Define the array of leds
CRGB leds[MAX_LEDS];

uint16_t NUM_LEDS;

struct simpap simpap_ctx;
static uint16_t start, stop;

static struct state
{
    uint16_t iteration;
    uint16_t num_leds;
    uint8_t brightness;
    uint8_t animation;
    struct animation_config* config;
} state_t;

void simpap_send_char(uint8_t ch);
void simpap_handler(uint8_t* data, uint8_t len);

bool state_check(const struct state* state_t);
bool state_update(struct state* state_t);
void state_save(const struct state* state_t);
bool state_load(struct state* state_t);
void state_print(const struct state* state_t);
void state_reset(struct state* state_t);

void print(const char *__fmt, ...)
{
#ifdef DEBUG
    char buf[50] = { 0 };
    va_list va;
    va_start(va, __fmt);
    vsprintf(buf, __fmt, va);
    va_end(va);

    simpap_send(&simpap_ctx, (uint8_t*)buf, COUNT_OF(buf));
#endif
}

bool state_check(const struct state* state_t)
{
    if(state_t->num_leds > MAX_LEDS){
        return false;
    }

    bool valid_id = false;
    for(uint8_t i = 0; i < CONFIGS_SIZE; i++){
        if(state_t->animation == configs[i]->id){
            valid_id = true;
        }
    }

    if(!valid_id){
        return false;
    }

    if(state_t->config == NULL){
        return false;
    }

    return true;
}

void state_print(const struct state* state_t)
{
    // print("ok (anim: %X)", state_t->animation);
    simpap_send(&simpap_ctx, (uint8_t*)"ok (anim)", 9);
}

// SoftwareSerial toSlave(10, 11);
void simpap_send_char(uint8_t ch)
{
    Serial.write(ch);
}

void simpap_handler(uint8_t* data, uint8_t len)
{
    in_comm = false;
    simpap_send_char(ACK);

    uint16_t cmd = get_u16((data + COMMAND_OFFSET));

    // Init packet (set number of leds)
    if(cmd == COMM_INIT_MSG) {
        // digitalWrite(LED_BUILTIN, HIGH);
        NUM_LEDS = (uint16_t)get_u32((data + PAYLOAD_OFFSET));

        if(NUM_LEDS > MAX_LEDS){
            return;
        }

        state_t.num_leds = NUM_LEDS;
        state_save(&state_t);

        return;
    }

    if(cmd == COMM_SET_BRIGHT_MSG) {
        uint32_t brightness = get_u32((data + PAYLOAD_OFFSET));

        if(brightness > 255){
            brightness = 255;
        }

        state_t.brightness = static_cast<uint8_t>(brightness);
        FastLED.setBrightness(state_t.brightness);

        state_save(&state_t);

        return;
    }

    // Set animation (animation with parameters)
    if(true) {
        /* Apply animation */
        for(uint16_t i = 0; i < COUNT_OF(configs); i++) {
            if(configs[i]->id != cmd) {
                continue;
            }

            state_t.animation = configs[i]->id;
            state_t.config = configs[i];
            ledfx_state_reset();

            uint8_t params_num = get_u8(data + PARAMS_NUM_OFFSET);
            for(uint8_t i = 0; i < params_num; i++){
                uint32_t value = get_u32((data + PAYLOAD_OFFSET + i*sizeof(uint32_t)));
                ledfx_set_param(i, value);
            }

            state_save(&state_t);
        }

        return;
    }

    // unknown
    // print("nok (unknown msg)");
    simpap_send(&simpap_ctx, (uint8_t*)"nok (unknown msg)", 17);
}

bool state_update(struct state* state_t)
{
    state_t->iteration++;

    ledfx_effect(state_t->animation, leds, state_t->num_leds);
    return true;
}

void state_save(const struct state* state_t)
{
    if(!state_check(state_t)){
        return;
    }

    EEPROM.put(MEM_STATE_ADDRESS, *state_t);
    EEPROM.put(MEM_ANIMATION_STATE_ADDRESS, animation_t);
    for(int i = 0; i < state_t->config->num; i++) {
        uint32_t address = MEM_ANIMATION_PARAMS_ADDRESS + sizeof(uint32_t)*i;
        EEPROM.put(address, animation_t.params[i]);
    }
    // This flag is used only to check that config was saved
    bool state_new = true;
    EEPROM.put(MEM_NEW_STATE_ADDRESS, state_new);
}

bool state_load(struct state* state_t)
{
    // Check if config exist in memory
    bool is_config_new = false;
    if(EEPROM.get(MEM_NEW_STATE_ADDRESS, is_config_new)) {
        state_reset(state_t);
        EEPROM.get(MEM_STATE_ADDRESS, *state_t);
        EEPROM.get(MEM_ANIMATION_STATE_ADDRESS, animation_t);

        // Assign config based on state_t->animation
        for(uint16_t i = 0; i < COUNT_OF(configs); i++) {
            if(configs[i]->id != state_t->animation) {
                continue;
            }

            state_t->config = configs[i];
        }

        // Read config params
        animation_t.params = (uint32_t*)malloc(state_t->config->num*sizeof(uint32_t));
        for(int i = 0; i < state_t->config->num; i++) {
            uint32_t address = MEM_ANIMATION_PARAMS_ADDRESS + sizeof(uint32_t)*i;
            EEPROM.get(address, animation_t.params[i]);
        }
    }

    if(!state_check(state_t)) {
        // print("nok (fail mem read)");
        simpap_send(&simpap_ctx, (uint8_t*)"nok (fail mem read)", 19);
        return false;
    }

    return true;
}

void state_reset(struct state* state_t)
{
    state_t->iteration = 0;
    state_t->num_leds = 10;
    state_t->brightness = 0xFF;
    state_t->animation = 0x44;
    state_t->config = configs[3];
    ledfx_state_reset();
}

ISR(WDT_vect)
{
	simpap_send(&simpap_ctx, (uint8_t*)"wdt fired", 10);
	digitalWrite(LED_BUILTIN, HIGH);
}

void setup()
{
    Serial.begin(9600);
    while (!Serial) { ; }
    Serial.flush();

    pinMode(LED_BUILTIN, OUTPUT);
    pinMode(PIN_RESET, INPUT);
    pinMode(PIN_DEBUG, OUTPUT);
    pinMode(PIN_HEARTBEAT, OUTPUT);
    digitalWrite(LED_BUILTIN, LOW);
    digitalWrite(PIN_DEBUG, LOW);
    digitalWrite(PIN_HEARTBEAT, HIGH);

    // Configure LED strip
    set_max_power_in_volts_and_milliamps(MAX_VOLTS, MAX_AMPS*1000);
    FastLED.addLeds<WS2812B, DATA_PIN, GRB>(leds, MAX_LEDS);

    simpap_init(&simpap_ctx);

    ledfx_init();

    // Read configuration from EEPROM if exist
    if(digitalRead(PIN_RESET) || !state_load(&state_t)) {
        // Initial state - Rainbow
        simpap_send(&simpap_ctx, (uint8_t*)"load failed", 11);
        state_reset(&state_t);
        state_save(&state_t);
    }

	cli();//stop interrupts

	// Configure main cycle timer
	TCCR1A = 0;// set entire TCCR1A register to 0
 	TCCR1B = 0;// same for TCCR1B
 	TCNT1  = 0;//initialize counter value to 0
 	// set compare match register for 1hz increments
    // 28 Hz ~ 35 ms
 	OCR1A = 557;// = (16*10^6) / (28*1024) - 1 (must be <65536)
 	// turn on CTC mode
 	TCCR1B |= (1 << WGM12);
 	// Set CS10 and CS12 bits for 1024 prescaler
 	TCCR1B |= (1 << CS12) | (1 << CS10);  
 	// enable timer compare interrupt
 	TIMSK1 |= (1 << OCIE1A);

	// Configure Watchdog
	wdt_disable();
	wdt_enable(WDTO_1S);
	// Enable WDT interrupt and WDT system reset
	WDTCSR |= (1 << WDE) | (1 << WDIE);

	sei(); // allow interrupts
}

ISR(TIMER1_COMPA_vect){
    update = true;
    heart_state = !heart_state;
}

void loop()
{
    if((stop - start) > CYCLE_MAX_DURATION) {
        simpap_send(&simpap_ctx, (uint8_t*)"nok (overrun)", 13);
    }
    start = millis();
    digitalWrite(PIN_HEARTBEAT, heart_state);
    heart_state = !heart_state;
    wdt_reset();

    /* Serial input processing */
    while (Serial.available()) {
        uint8_t ch = Serial.read();
        if(ch == START_COMM) {
            simpap_send_char(ACK);
            in_comm = true;
            continue;
        }
        if(in_comm){
            int8_t rc = simpap_accept_char(&simpap_ctx, ch);
            // Message is ok and handler was called
            if(rc == 1){
                break;
            }
            // Parsing error or message is damaged
            if(rc != 0) {
                in_comm = false;
                simpap_send_char(ACK);
            }
        }
    }

    /* LED update */
    if(update and !in_comm){
        if(state_update(&state_t)) {
            FastLED.setBrightness(state_t.brightness);
            FastLED.show();
        }
        update = false;
    }

    stop = millis();
}

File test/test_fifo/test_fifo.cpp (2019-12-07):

#include <unity.h>
#include <stdint.h>

#include <fifo.h>

// void setUp(void) {
// // set stuff up here
// }

// void tearDown(void) {
// // clean stuff up here
// }
//
//
#define BUFFER_SIZE 255

void test_size(void) {
    FIFO<uint8_t>* f = new FIFO<uint8_t>(BUFFER_SIZE);
    TEST_ASSERT_EQUAL(f->getsize(), BUFFER_SIZE);
    delete f;
}

void test_available(void){
    FIFO<uint8_t>* f = new FIFO<uint8_t>(BUFFER_SIZE);
    TEST_ASSERT_EQUAL(f->available(), 0);
    f->put(1);
    f->put(2);
    f->put(3);
    f->put(4);
    f->put(5);
    TEST_ASSERT_EQUAL(f->available(), 5);
    delete f;
}

void test_clear(void){
    FIFO<uint8_t>* f = new FIFO<uint8_t>(BUFFER_SIZE);
    TEST_ASSERT_EQUAL(f->available(), 0);
    f->put(1);
    f->put(2);
    f->put(3);
    f->put(4);
    f->put(5);
    TEST_ASSERT_EQUAL(f->available(), 5);
    f->clear();
    TEST_ASSERT_EQUAL(f->available(), 0);
    TEST_ASSERT_EQUAL(f->get(), 0);
    delete f;
}

void test_basic(void) {
    int count = 10;
    FIFO<uint32_t>* f = new FIFO<uint32_t>(BUFFER_SIZE);
    TEST_ASSERT_EQUAL(f->available(), 0);
    for(int i = 0; i < count; i++){
        f->put(i);
    }
    TEST_ASSERT_EQUAL(f->available(), count);
    for(int i = 0; i < count; i++){
        TEST_ASSERT_EQUAL(f->get(), i);
    }
    delete f;
}

void testsuite(){
    UNITY_BEGIN();
    RUN_TEST(test_size);
    RUN_TEST(test_available);
    RUN_TEST(test_clear);
    RUN_TEST(test_basic);
    UNITY_END();
}

#ifdef ARDUINO

#include <Arduino.h>

void setup() {
    // NOTE!!! Wait for >2 secs
    // if board doesn't support software reset via Serial.DTR/RTS
    delay(2000);

    UNITY_BEGIN();
    RUN_TEST(test_size);
    RUN_TEST(test_available);
    RUN_TEST(test_clear);
    RUN_TEST(test_basic);
    UNITY_END();
}

void loop() {
    digitalWrite(13, HIGH);
    delay(100);
    digitalWrite(13, LOW);
    delay(500);
    // Serial.end();
}

#else

int main(int argc, char** main){
    testsuite();

    return 0;
}

#endif

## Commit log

2019-05-14 Add hardware part
    Board is drawn. I decided to not to install reset button and use test point between reset pin and ground
    [ambient.kicad_pcb, ambient.sch, components.csv]
2019-06-13 hw: Get rid of "ambient" name -> now "blueled"
    [blueled.kicad_pcb, blueled.sch]
2019-06-13 hw: Remove components.csv
    [components.csv]
2019-06-17 Add ISCP port to schematics
2019-07-28 docs: Add first issue and template
    I think it is useful to track, describe and explain issues which I face
    during the development. Issues on the gitlab/github are useful but they
    are suited for implementation problems/bugs. These issues more like
    design/architecture-ish
2019-07-28 hw: Mainly refactoring + add switch to the schematics
    [blueled.kicad_pcb]
2019-07-29 Rename relay issui and add new results of research
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2019-08-07 docs: Add SPI EEPROM chip's datasheet
2019-08-07 Remove some file-formats from gitignore (KiCAD's)
2019-08-07 New version of hardware
    * SPI chip is added but not routed
    * Power switch MOSFET is added
    * Power flags added
    * SPI pins are moved to the right
    [blueled.kicad_pcb, blueled.sch]
2019-08-10 Update status of the MOSFET issue
2019-08-10 Add source link for the P-MOSFET reverse polarity protection
2019-08-10 Make pads for SMD components bigger and general rerouting
    [blueled.kicad_pcb, blueled.sch]
2019-08-18 HW: Remove big pads for MOSFET
    [blueled.kicad_pcb]
2019-08-25 docs: AT command sequence of current slave and master configurations
2019-08-25 Add region for VIN
    [blueled.kicad_pcb]
2019-08-25 Minor updates
    [blueled.kicad_pcb]
2019-09-01 Rev 0.1
    [blueled.kicad_pcb]
2019-09-01 Add gerber files sent to manufacture
    [blueled-B_Cu.gbr, blueled-B_Mask.gbr, blueled-B_SilkS.gbr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]
2019-09-24 hw: Last changes
    [blueled.kicad_pcb]
2019-10-22 add: src folder with blink sample
2019-11-26 add(hw): assign new bigger footprints
    [blueled.kicad_pcb, blueled.sch]
2019-12-07 add(hw): moving to new layout
    [blueled.kicad_pcb]
2019-12-07 fix(test): delete object otherwise stack overflows
    [test_fifo.cpp]
2019-12-30 add: Makefile to combined HEX experiment
    It is used to combine firmware and bootloader into one
    HEX file and upload it into arduino
2019-12-30 add(pio): Add targets for vanilla arduino and uploading through ISP
2020-03-31 fix: pio config for wireless connection
2020-04-01 add: start update of hw to new rev
    [blueled.kicad_pcb, blueled.sch]
2020-04-12 add: footprint for XKB7070-Z/X
2020-04-12 add: footprint for Murata SMD resonator
2020-04-12 add: schematics update
    [blueled.kicad_pcb, blueled.sch]
2020-04-19 fix: name of XKB switch footprint
2020-04-19 add: finish layouting
    [blueled.kicad_pcb, blueled.sch]
2020-04-23 add: tantalum capacitor to the linear regulator
    [blueled.sch]
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2020-04-23 add: missing 3d models
    [CSTNE.step, HC-05.step, kf120-5.0-3p.step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]
2020-04-23 fix: configure pass to project 3dmodels
    [blueled.kicad_pcb, blueled.sch]
2020-04-23 add: missing Barrel Jack model
    [blueled.kicad_pcb, dc-005-5a-2_0.step]
2020-04-24 fix: colorize 3D models
    [CSTNE.step, dc-005-5a-2_0.step, xkb7070-z.step]
2020-04-24 fix: move tantalum capacitor from switch
    [blueled.kicad_pcb]
2020-04-25 fix: MOSFET pin mapping and better layouting
    [blueled.kicad_pcb]
2020-04-27 refactor: get rid of switch cases for readability and easier addition of new animations
    I googled and seems like on small sets switch-case is the same in speed as for loop
    So, not a big deal but I want to try it this way
2020-04-29 fix: +3.3 net + page description and date
    [blueled.sch]
2020-04-29 add: jumpers to pcb layout
    [blueled.kicad_pcb, blueled.sch]
2020-06-01 add: hw snapshot
    [blueled.sch]
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2020-06-30 fix: remove debug code
    [main.cpp]
2020-07-17 fix: minor animation changes
    [main.cpp]
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2020-07-26 fix: LED array initialization after loading from EEPROM
    [main.cpp]
2020-07-26 fix: handle simpap_accept_char return code
    [main.cpp]
2020-09-13 fix: don't use malloc
    [main.cpp]
2020-09-13 fix: pre-commit hook don't add staged files
2020-09-19 fix: save state after it's reset
    [main.cpp]
2020-10-01 fix: many minor fixes
    [main.cpp]
2020-10-01 fix: slow down serial + add fire animation
    [simpap_protocol.py]
2020-10-04 fix: finally stable communication
    [main.cpp, simpap_protocol.py]
2020-10-25 fix: working animation parametrization
    [main.cpp, simpap_protocol.py]
2020-10-28 fix: size in animation config in uint32_t not in bytes and config saving
    [main.cpp]
2020-10-28 fix: gradient with 2 colors
    [simpap_protocol.py]
2020-10-28 fix: don't accept commands if not in communication
    [main.cpp]
2020-10-30 fix: many minor fixes with communication
    [main.cpp]
2020-11-01 fix: use CPP casting
    [main.cpp]
2020-11-01 fix: last config ID constant
    [main.cpp]
2020-11-02 fix: use sizeof() instead of magic value
    [main.cpp]
2020-11-02 fix: ws2812b have GRB instead of RGB
    [main.cpp]
2020-11-04 refactor: cleaning of schematics
    [blueled.sch]
2020-11-07 add: heartbeat pin
    [blueled.sch]
2020-11-07 add: DC-to-DC converter + redone schematics
    [blueled.sch]
2020-11-07 fix(hw): more minor fixes
    [blueled.sch]
2020-11-09 fix: max number of LEDs
    Looks like with 5A it can control ~96 LEDs (52.5 mA per unit)
2020-11-19 fix: minor adjustments of the schematics
    [blueled.sch]
2020-11-21 add(hw): value to resistor
    [blueled.sch]
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2020-11-23 fix: remove unused function + fix CRC endianness
    [simpap_protocol.py]
2020-11-23 fix: set_leds() didn't work
    [main.cpp]
2020-11-24 fix: set number of received parameters to animation state
    [main.cpp]
2020-11-26 add(hw): updating BOM
    [blueled.sch]
2020-11-26 fix: heartbeat pin wasn't working
    [main.cpp]
2020-11-26 fix: set_total_params() is not a thing anymore
    [main.cpp]
2020-11-26 add(hw): resistor for ENA of DC/DC
    [blueled.sch]
2020-11-27 fix: wrong variable name
    [main.cpp]
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2020-12-01 fix: increase rate up to 28 Hz (35 ms)
    Also did some test how stable it works. Looks good
    [main.cpp]
2020-12-05 add: better terminal block for led connection
    [blueled.sch]
2020-12-05 add: enable correct brown-out-detection level on the board
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2020-12-05 fix: EN should be floating
    [blueled.sch]
2020-12-05 add: power supply is based on LM25085
    [blueled.sch]
2020-12-05 add: missing comments (more to go)
    [blueled.sch]
2020-12-05 fix(hw): more changes to power supply scheme
    [blueled.sch]
2020-12-07 fix(hw): fix rules checker issues
    [blueled.sch]
2020-12-07 add(hw): BOM updates
    [blueled.sch]
2020-12-09 add(hw): more components in BOM
    [blueled.sch]
2020-12-10 add(hw): more BOM updates
    [blueled.sch]
2020-12-13 add(hw): more footprints and boms
    [blueled.sch]
2020-12-19 add(hw): some capacitors to BOM
    [blueled.sch]
2020-12-20 add(hw): almost done with assigning capacitors
    [blueled.sch]
2020-12-21 add(hw): update resistors in BOM
    [blueled.sch]
2020-12-26 add(hw): component assignment is done
    [blueled.sch]
2020-12-26 add(hw): CS-FLASH connection
    [blueled.sch]
2020-12-26 refactor(hw): minor fixes
    [blueled.sch]
2020-12-26 add(hw): board sizes according to ISO/IEC 7810 ID-1
    [blueled.kicad_pcb]
2020-12-26 refactor(hw): removing old traces and rearrangments
    [blueled.kicad_pcb]
2020-12-28 add(hw): footprints for terminal blocks
    [blueled.sch]
2020-12-28 fix(hw): replace VIN with +5V
    [blueled.sch]
2020-12-28 add(hw): initial layout for v2.0
    [blueled.kicad_pcb]
2020-12-28 add(hw): more layout improvements
    [blueled.kicad_pcb]
2020-12-29 add(hw): minor adjacements of output filter
    [blueled.sch]
2020-12-29 add(hw): a lot of progress in layouting + bug fixes
    [blueled.kicad_pcb, blueled.sch]
2020-12-30 add(hw): level shifter + layout progress
    [blueled.kicad_pcb, blueled.sch]
2020-12-30 add(hw): routed level shifter
    [blueled.kicad_pcb]
2020-12-30 add(hw): almost finished layout
    [blueled.kicad_pcb]
2021-01-01 add(hw): thermal vias and vias on high current traces
    https://www.eevblog.com/forum/projects/via-stitching-for-high-current-traces/
    [blueled.kicad_pcb]
2021-01-01 fix(hw): just moved a label on silk screen
    [blueled.kicad_pcb]
2021-01-01 fix(hw): change input cap + minor fixes
    [blueled.kicad_pcb, blueled.sch]
2021-01-01 fix(hw): minor adjustments (shorter current loop)
    [blueled.kicad_pcb, blueled.sch]
2021-01-02 add(hw): labels and 3D models
    [blueled.kicad_pcb, blueled.sch, terminal-block-2.stp]
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2021-01-12 add: new BOM and update *.sch to new symbol lib
    [blueled.csv, blueled.sch]
2021-01-13 fix(hw): change BJT to MOSFET to control HC-05 power
    [blueled.kicad_pcb, blueled.sch]
2021-01-14 fix: correct triggering of show()
    [main.cpp]
2021-01-31 refactor: change page settings
    [blueled.sch]
2021-01-31 add: MOSFET for HC-05 power switch
    [blueled.kicad_pcb, blueled.sch]
2021-01-31 Revert "add: integration with WS2812B"
    This reverts commit f4b76e52d401eaebef58efb1243d73c20fc64a66.
    [main.cpp]
2021-01-31 Revert "fix: correct triggering of show()"
    This reverts commit 2dfcc8b9fa19fba6536fb9137378aa67650c1268.
    [main.cpp]
2021-01-31 fix: revert changes from other branch
    [main.cpp]
2021-01-31 fix: update silkscreen labels
    [blueled.kicad_pcb]
2021-01-31 add: new gerbers
    [blueled-B_Cu.gbr, blueled-B_Mask.gbr, blueled-B_SilkS.gbr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]
2021-09-01 fix: baudrate to HC-05
    [main.cpp]
2021-09-01 add(hw): new BOM and gerbers
    [BOM.csv]
